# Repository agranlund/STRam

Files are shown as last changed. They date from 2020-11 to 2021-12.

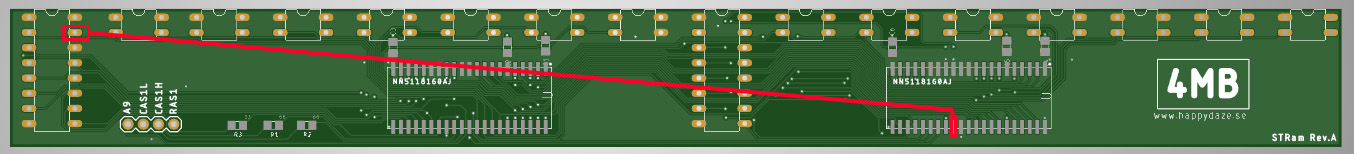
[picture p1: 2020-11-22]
board_fix.jpg

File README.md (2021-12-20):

[fixing with a bodge wire]: /board_fix.jpg

# Atari 520ST(M)<br>4MB RAM Expansion

*Tested on* ***C070243 Rev.I*** *, your mileage may vary.*

---

### Important

1. The board needs **[fixing with a bodge wire]**

2. The expansion board **must** be installed<br>
   directly onto the motherboard.<br>

   Using sockets **won't** leave enough<br>clearance for the keyboard

---

### BOM

| | Component | Value | Size | Package |
|:--:|:---:|:-----:|:----:|:---:|
| | **C1** - **C6**  | 100nF | 0805 | |
| | **R1** - **R2**  | 68Ω | 0805 | |
| | **R3** | 33Ω | 0805 | |
| 2x | **5118160 DRAM** | | | SOJ42 |

---

### Installation

- De-solder the existing RAM.

- Solder the expansion board in place.

- Solder the four wires from the expansion<br>
  board to the motherboard.

  Signals: **MAD9**, **CAS1L**, **CAS1H**, **RAS1**

  **MAD9** can usually only be found on the **MMU**

  The **CAS** & **RAS** pins can be soldered to on the<br>
  underside of the motherboard as well as,<br>
  ***on some boards***, on the topside as well.

    |  Name | MMU Pin |
    |:-----:|:-------:|
    |  RAS1 |    18   |
    | CAS1L |    21   |
    | CAS1H |    22   |
    |  MAD9 |    64   |

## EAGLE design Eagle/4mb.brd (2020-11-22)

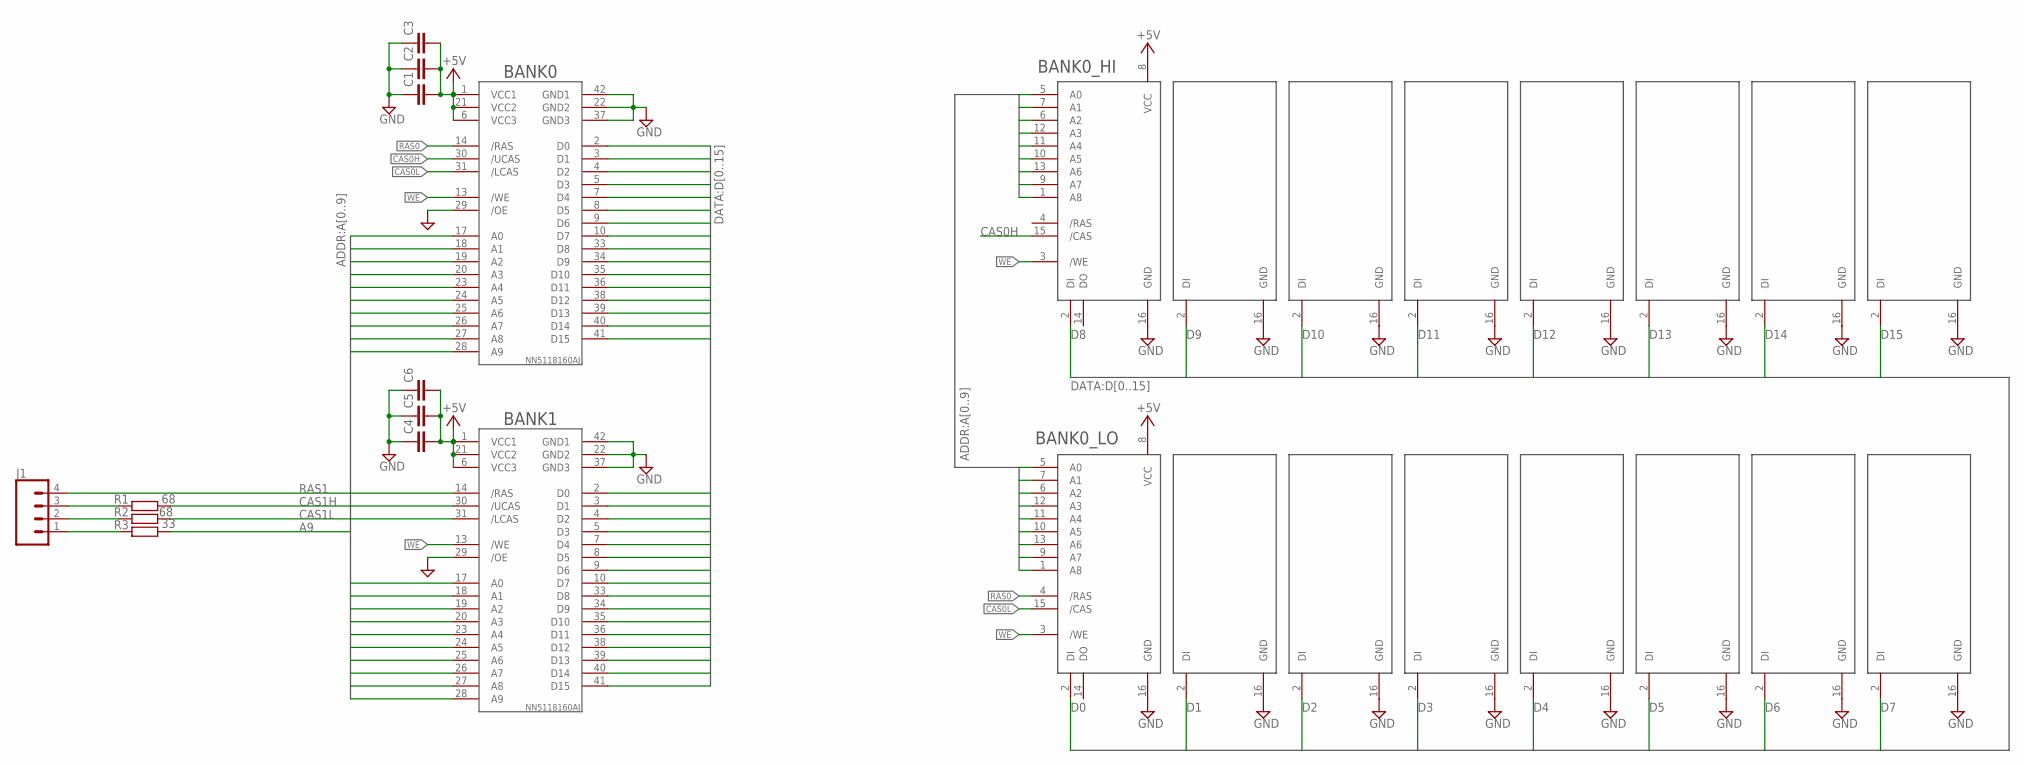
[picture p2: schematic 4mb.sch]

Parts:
C1, C2, C3, C4, C5, C6: C-EUC0805; C0805
J1: CONN_04PTH; 1X04
R1, R2: 68; R0805
R3: 33; R0805
U$1, U$2: NN5118160AJ; SOJ127P1117X376-42
U$3, U$11: ST_DRAM; DIL16
U$4, U$5, U$6, U$7, U$8, U$9, U$10, U$12, U$13, U$14, U$15, U$16, U$17, U$18: ST_DRAM_D; ST_DRAM_SOCKET_MINIMAL

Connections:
+5V: C1.2, C2.2, C3.2, C4.2, C5.2, C6.2, U$1.1 (VCC1), U$1.6 (VCC3), U$1.21 (VCC2), U$2.1 (VCC1), U$2.6 (VCC3), U$2.21 (VCC2), U$3.8 (VCC), U$11.8 (VCC)
A0: U$1.17 (A0), U$2.17 (A0), U$3.5 (A0), U$11.5 (A0)
A1: U$1.18 (A1), U$2.18 (A1), U$3.7 (A1), U$11.7 (A1)
A2: U$1.19 (A2), U$2.19 (A2), U$3.6 (A2), U$11.6 (A2)
A3: U$1.20 (A3), U$2.20 (A3), U$3.12 (A3), U$11.12 (A3)
A4: U$1.23 (A4), U$2.23 (A4), U$3.11 (A4), U$11.11 (A4)
A5: U$1.24 (A5), U$2.24 (A5), U$3.10 (A5), U$11.10 (A5)
A6: U$1.25 (A6), U$2.25 (A6), U$3.13 (A6), U$11.13 (A6)
A7: U$1.26 (A7), U$2.26 (A7), U$3.9 (A7), U$11.9 (A7)
A8: U$1.27 (A8), U$2.27 (A8), U$3.1 (A8), U$11.1 (A8)
A9: R3.2, U$1.28 (A9), U$2.28 (A9)
CAS0H: U$1.30 (/UCAS), U$3.15 (/CAS)
CAS0L: U$1.31 (/LCAS), U$11.15 (/CAS)
CAS1H: R1.2, U$2.30 (/UCAS)
CAS1L: R2.2, U$2.31 (/LCAS)
D0: U$1.2 (D0), U$2.2 (D0), U$11.2 (DI)
D1: U$1.3 (D1), U$2.3 (D1), U$12.2 (DI)
D2: U$1.4 (D2), U$2.4 (D2), U$13.2 (DI)
D3: U$1.5 (D3), U$2.5 (D3), U$14.2 (DI)
D4: U$1.7 (D4), U$2.7 (D4), U$15.2 (DI)
D5: U$1.8 (D5), U$2.8 (D5), U$16.2 (DI)
D6: U$1.9 (D6), U$2.9 (D6), U$17.2 (DI)
D7: U$1.10 (D7), U$2.10 (D7), U$18.2 (DI)
D8: U$1.33 (D8), U$2.33 (D8), U$3.2 (DI)
D9: U$1.34 (D9), U$2.34 (D9), U$4.2 (DI)
D10: U$1.35 (D10), U$2.35 (D10), U$5.2 (DI)
D11: U$1.36 (D11), U$2.36 (D11), U$6.2 (DI)
D12: U$1.38 (D12), U$2.38 (D12), U$7.2 (DI)
D13: U$1.39 (D13), U$2.39 (D13), U$8.2 (DI)
D14: U$1.40 (D14), U$2.40 (D14), U$9.2 (DI)
D15: U$1.41 (D15), U$2.41 (D15), U$10.2 (DI)
GND: C1.1, C2.1, C3.1, C4.1, C5.1, C6.1, U$1.22 (GND2), U$1.29 (/OE), U$1.37 (GND3), U$1.42 (GND1), U$2.22 (GND2), U$2.29 (/OE), U$2.37 (GND3), U$2.42 (GND1), U$3.16 (GND), U$4.16 (GND), U$5.16 (GND), U$6.16 (GND), U$7.16 (GND), U$8.16 (GND), U$9.16 (GND), U$10.16 (GND), U$11.16 (GND), U$12.16 (GND), U$13.16 (GND), U$14.16 (GND), U$15.16 (GND), U$16.16 (GND), U$17.16 (GND), U$18.16 (GND)
unnamed: J1.2, R2.1
unnamed: J1.1, R3.1
unnamed: J1.3, R1.1
RAS0: U$1.14 (/RAS), U$11.4 (/RAS)
RAS1: J1.4, U$2.14 (/RAS)
WE: U$1.13 (/WE), U$2.13 (/WE), U$3.3 (/WE), U$11.3 (/WE)

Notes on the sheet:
BANK0
BANK1
BANK0_HI
BANK0_LO

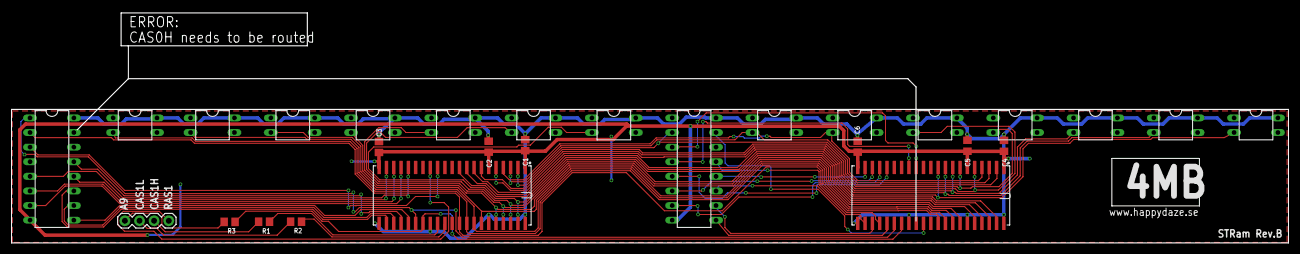
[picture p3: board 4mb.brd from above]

Board: 2 copper layers, 222.0 x 23.2 mm, 28 parts (0 on the bottom side), 38 nets.

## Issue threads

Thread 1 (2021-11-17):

Trying to upload to OSH Park, no board outline in Gerbers.

Rory-McMahon, 2021-11-17:
This is the error I get.

Failure (critical): We couldn't find the board outline.

Thank you,

agranlund, 2021-11-21:
Hi!
I can’t remember which PCB house I exported those Gerbers for, but I think it was using the settings/script provided by JLCPCB.

It was many years since I used OSHPark but I do believe They accept eagle files directly (and they will generate the Gerber from that on their side)
I’d try that method and upload the Eagle, and double check that the board looks ok in their preview.

alternatively export Gerbers from The Eagle file yourself using OSHPark specifications, they probable have scripts available.

Cheers,
—Anders

Skickat från min iPhone

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

hunsra, 2021-12-18:
Tried exporting from Gerber files from Eagle CAD 9.6.2 for upload to JLPCB and the board dimension are empty.  However, using the "Statistics" view in Eagle, I was able to find out the board is 222.01mm x 40.06mm, so I entered that into JLPCB's interface.  Hopefully this is correct.  I'll post my findings when I receive the boards.

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
.

Verault, 2023-07-10:
I used JLCpcb to get these. They should be here any day but there were no issues when I sent them to be fabbed.

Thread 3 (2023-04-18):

White screen on 520 ST C070243 REV C

HobNobblin, 2023-04-18:
I'm getting a consistent white screen and no activity on my 520st fm. Usually there are black vertical bars for a few moments then a constant white screen. Prior to removing the original ram chips there was a bodge wire in place from pin 8 (I think it's pin 8 anyway) to pin 4 of ram chip U32.
I'll try to scope some of the ram and mmu activity to see if I can see anything.

HobNobblin, 2023-04-18:
Looks like one of the ram lines was grounded due to an exposed trace.

Closed 2023-04-18.

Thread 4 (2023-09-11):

Cannot get board to work at 4MB, only 1MB when pulling u15 MMU to ground.

Verault, 2023-09-11:
Hello. I just finished installing this board On my North American NTSC 520ST. I have the appropriate jumper wire as depicted in your photo. I got the idea to install a switch on the A9 line from an episode of Adrians Digital basement where I found out about your 4MB board:  https://youtu.be/uqWCmKcaZtI?t=1487

When I boot the computer, to either GEM or my Atari ST diags cartridge with it set to 4MB I just get screen garbage:
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

And if I boot with the same diag cart and have the switch set to pull a9 to ground it works:
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

Also on the ADB video it says you need to reverse lines CAS1L and CAS1H they are mislabeled. But I dont see this on the github site. Is that not something I need to worry about? I think I am pretty close to getting this thing working. what do you think? Please excuse the terrible video. I am using a small 9" television and RF on my workbench for testing.

Verault, 2023-09-11:
So the issue was my switch. I wasnt using the proper multi pole switch and it needed an additional ground for the a9 line when switching to 1MB. Completely my fault! And I can tell the cas1H and Cas1L work fine as is so I dont know why the video mentions swapping them.

Ran Memory diags in both 1MB and 4MB mode and they both pass fine.

Great board and thank you!

Closed 2023-09-11.

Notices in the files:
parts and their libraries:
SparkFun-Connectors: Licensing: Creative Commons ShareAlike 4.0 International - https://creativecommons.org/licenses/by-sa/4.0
